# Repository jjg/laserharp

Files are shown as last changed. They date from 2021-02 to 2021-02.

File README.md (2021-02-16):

# laserharp

Play music by plucking strings made from laserbeams!

The instrument is composed of two separate components (laser bar and receiver) which are currently designed to be mounted in a 30" door frame.  A note is played when one of the eight beams is broken.

## Repository Structure
+ [docs](./docs/) - Component and other documentation captured from other sources
+ [experiments](./experiments/) - Mostly test code to figure out how to get things working
+ [images](./images/) - Photos and renderings
+ [models](./models/) - 3D model files for printable components
    + [laser_base.scad](./models/laser_base.scad) - Semi-paramentric laser LED holder with fine aiming adjustment
+ [firmware.py](./firmware.py) - Micropython firmware for the ESP32

## Current Status

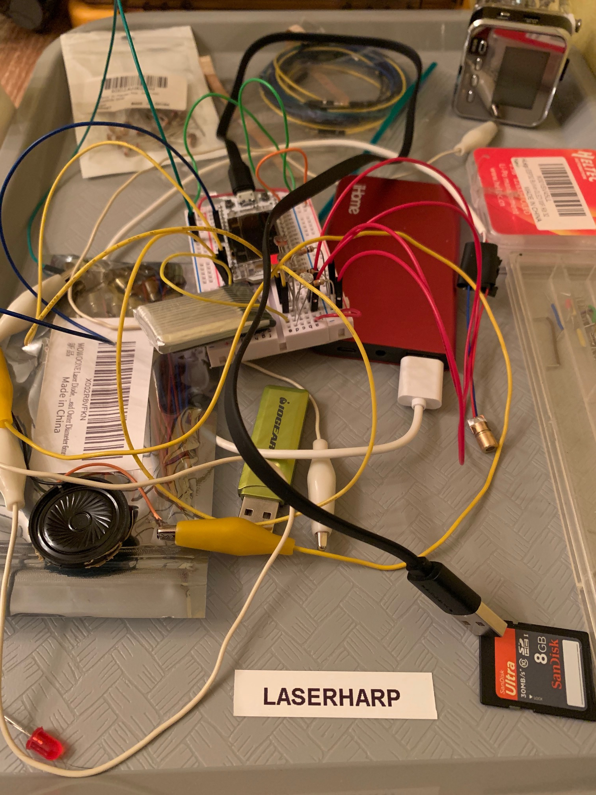
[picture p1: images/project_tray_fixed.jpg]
photo of tray full of parts


A functional (if not beautiful) prototype of the electronics and firmware has been completed and work is now focused on the physical components.  

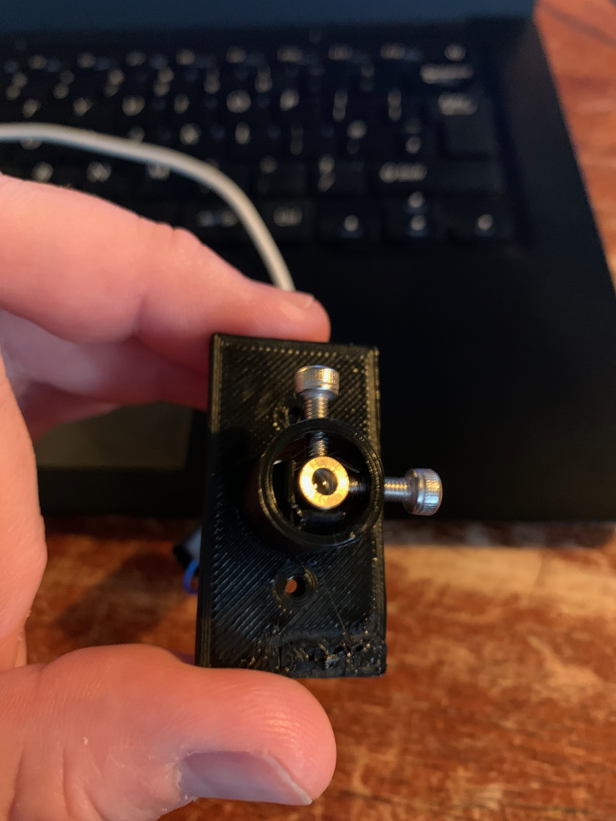
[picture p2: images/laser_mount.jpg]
photo of first version of laser mount


Once mounts for the lasers and sensors are complete these will be mounted on a full-size test rig to verify operation at full scale and test things like the difficulty of aiming the beams, etc.

## Theory of operation

8 laser beams (notes c to C) are aimed at 8 photoresisors connected on an ESP32.  The ESP32 scans the photoresistors and plays a note if the beam is interrupted.

## Hardware

* 1x [Heltec WiFi Kit 32](https://heltec.org/project/wifi-kit-32/)
* 1x 1000 mAh lithium battery
* 8x photoresistors
* 8x 10k resistors
* 1x 8ohm mini speaker
* 8x 5v ???mw red laser diodes

The ESP32 provides all the required functionality and the possibility for a wireless instrument interface in the future.  The Heltec board was selected because of its low-cost, compact construction and inclusion of a robust power supply (typically a weak point of most ESP32 designs).

TODO: add schematic

The photoresistors are connected to GPIO 32 through 39 using a voltage divider.  The speaker is simply connected between GPIO 14 and ground.

## Software

The current version of the [firmware](./firmware.py) scans each photoresistor once per second and when dark, plays the according note via PWM to a small speaker attached to pin 14.

## What's Next?

This completes the proof-of-concept stage so construction of the chassis using the selected components can begin.  The basic PWM "beeper" may be replaced with an amplified speaker or possibly an external WiFi/Bluetooth instrument connection.

## References

* https://www.instructables.com/Interfacing-Photoresistor-With-ESP32/
* https://docs.micropython.org/en/latest/library/pyb.DAC.html
* https://resource.heltec.cn/download/WiFi_Kit_32/WIFI_Kit_32_pinoutDiagram_V2.pdf
* https://micropython-on-wemos-d1-mini.readthedocs.io/en/latest/basics.html#beepers

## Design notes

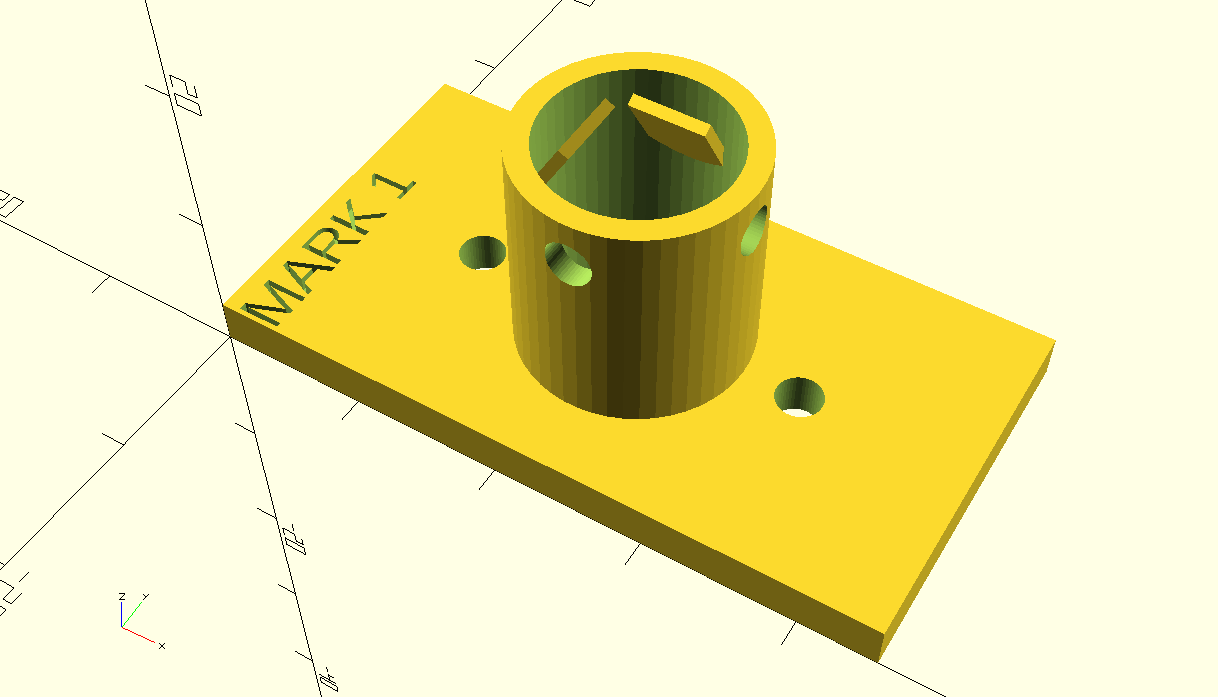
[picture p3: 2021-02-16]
images/laser_base.png

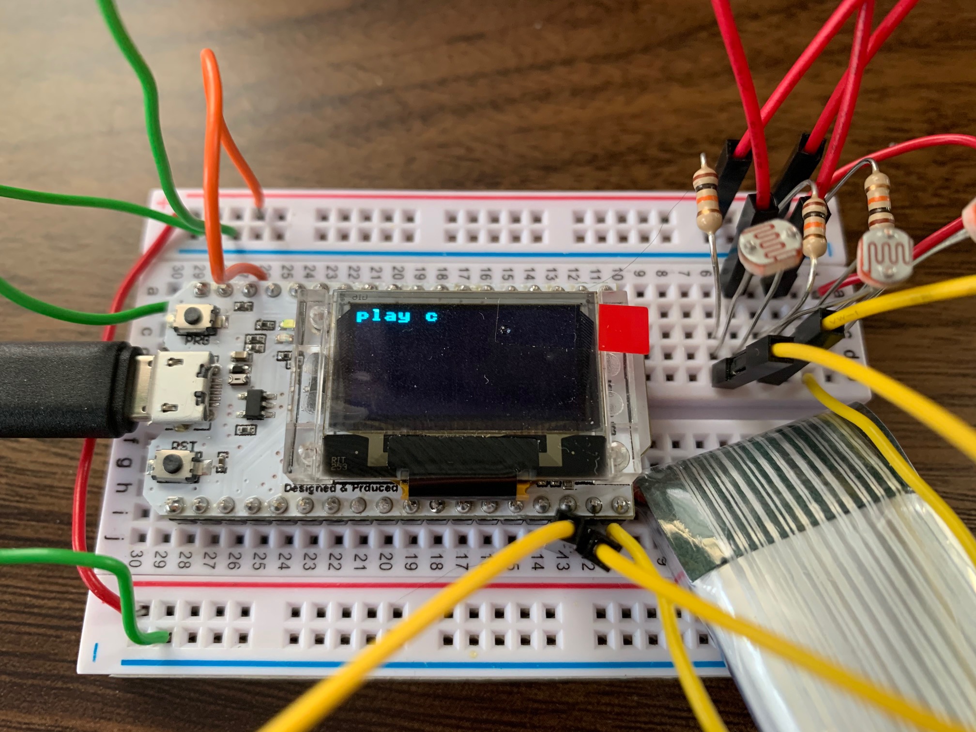
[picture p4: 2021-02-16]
images/oled_close_up.jpg

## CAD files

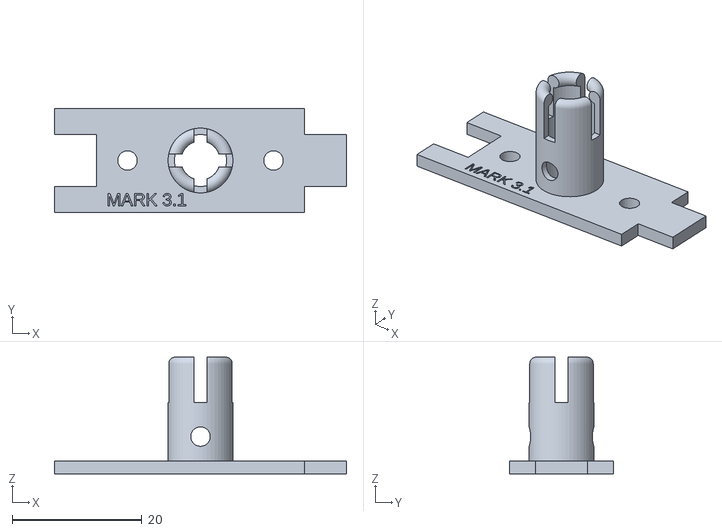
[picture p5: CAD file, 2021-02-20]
models/laser_base_m3_1.stl
45.0 x 16.0 x 18.0

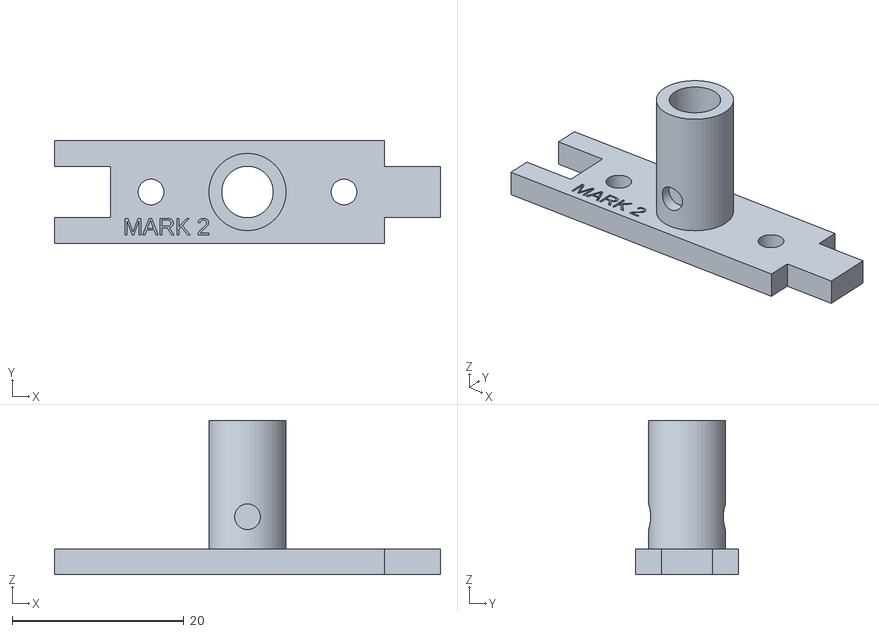
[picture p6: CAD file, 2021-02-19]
models/laser_base_m2.stl
45.0 x 12.0 x 18.0

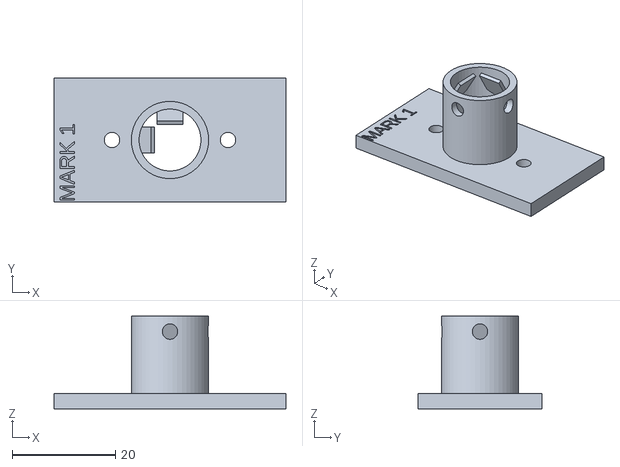
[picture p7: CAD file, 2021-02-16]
models/laser_base.stl
45.0 x 24.0 x 18.0

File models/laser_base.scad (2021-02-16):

VERSION = "MARK 1";
LASER_DIAMETER = 12; // actual: 6
LASER_LENGTH = 15; // actual: 14
BEAM_SPACING = 90;
SCREW_DIAMETER = 3;
WALL = 3;

$fn = 50;

difference(){
    
    // base
    cube([BEAM_SPACING / 2, LASER_DIAMETER * 2, WALL]);
    
    // mounting holes
    translate([BEAM_SPACING / 8, LASER_DIAMETER, -1]){
        cylinder(r=SCREW_DIAMETER / 2, h=6);
    }
    translate([(BEAM_SPACING / 2) - (BEAM_SPACING / 8), LASER_DIAMETER, -1]){
        cylinder(r=SCREW_DIAMETER / 2, h=6);
    }
    
    // laser insert hole
    translate([BEAM_SPACING / 4, LASER_DIAMETER, -1]){
        cylinder(r=LASER_DIAMETER / 2, h=6);
    }
    
    // version emblem
    translate([4,0,WALL-1]){
        rotate([0,0,90]){
            linear_extrude(1){
                text(VERSION, size=3);
            }
        }
    }
}

// laser holder
translate([BEAM_SPACING / 4, LASER_DIAMETER, WALL]){
    difference(){
        
        // post
        cylinder(r = (LASER_DIAMETER + WALL) / 2, h=LASER_LENGTH);
        
        // hole
        translate([0,0,-1]){
            cylinder(r = (LASER_DIAMETER / 2), h=LASER_LENGTH + 1);
        }
        
        // x adjustment screw hole
        translate([0,-WALL,LASER_LENGTH - WALL]){
            rotate([90, 0, 0]){
                cylinder(r=SCREW_DIAMETER / 2, h=WALL * 2);
            }
        }
        
        // y adjustment screw hole
        rotate([0,0,90]){
            translate([0,-WALL,LASER_LENGTH - WALL]){
                rotate([90, 0, 0]){
                    cylinder(r=SCREW_DIAMETER / 2, h=WALL * 2);
                }
            }
        }
    }
    
    // x spring
    translate([-WALL / 2 - 1,WALL * 2,LASER_LENGTH - (WALL * 2)]){
        rotate([30,0,0]){
            cube([WALL + 2, WALL / 4, WALL * 2]);
        }
    }
    
    // y spring
    rotate([0,0,90]){
        translate([-WALL / 2 - 1,WALL * 2,LASER_LENGTH - (WALL * 2)]){
            rotate([30,0,0]){
                cube([WALL + 2, WALL / 4, WALL * 2]);
            }
        }
    }
}

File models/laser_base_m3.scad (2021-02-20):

VERSION = "MARK 3.1";
LASER_DIAMETER = 8; // actual: 6
LASER_LENGTH = 15; // actual: 14
BEAM_SPACING = 90;
SCREW_DIAMETER = 3;
WALL = 2;

$fn = 50;

difference(){
    
    // base
    cube([BEAM_SPACING / 2, LASER_DIAMETER * 2, WALL]);
    
    // mounting holes
    translate([BEAM_SPACING / 8, LASER_DIAMETER, -1]){
        cylinder(r=SCREW_DIAMETER / 2, h=6);
    }
    translate([(BEAM_SPACING / 2) - (BEAM_SPACING / 8), LASER_DIAMETER, -1]){
        cylinder(r=SCREW_DIAMETER / 2, h=6);
    }
    
    // spacing cut-outs
    translate([-1,LASER_DIAMETER/2,-1]){
        cube([BEAM_SPACING / 12, LASER_DIAMETER, WALL + 2]);
    }
    translate([(BEAM_SPACING / 2 ) - (BEAM_SPACING / 12) + 1,LASER_DIAMETER+ (LASER_DIAMETER/2),-1]){
        cube([BEAM_SPACING / 12, LASER_DIAMETER, WALL + 2]);
    }
    translate([(BEAM_SPACING / 2 ) - (BEAM_SPACING / 12) + 1,- (LASER_DIAMETER / 2),-1]){
        cube([BEAM_SPACING / 12, LASER_DIAMETER, WALL + 2]);
    }
    
    // laser insert hole
    translate([BEAM_SPACING / 4, LASER_DIAMETER, -1]){
        cylinder(r=LASER_DIAMETER / 2, h=6);
    }
    
    // version emblem
    translate([8,1,WALL-1]){
        rotate([0,0,0]){
            linear_extrude(5){
                #text(VERSION, size=2);
            }
        }
    }
}

// laser holder
translate([BEAM_SPACING / 4, LASER_DIAMETER, WALL]){
    difference(){

        // post
        cylinder(r = (LASER_DIAMETER + WALL) / 2, h=LASER_LENGTH);
        
        // feed-through hole
        translate([0,0,-1]){
            cylinder(r = (LASER_DIAMETER / 2), h=LASER_LENGTH + 2);
        }
        
        // tension cut-outs
        translate([-LASER_DIAMETER,-WALL + (WALL / 2), LASER_LENGTH - (WALL * 3)]){
            cube([LASER_DIAMETER * 2, WALL, WALL * 4]);
        }
        rotate([0,0,90]){
            translate([-LASER_DIAMETER,-WALL + (WALL / 2), LASER_LENGTH - (WALL * 3)]){
                cube([LASER_DIAMETER * 2, WALL, WALL * 4]);
            }
        }
        
        // wiring hole
        translate([0,-WALL,(LASER_LENGTH / 4)]){
            rotate([90, 0, 0]){
                cylinder(r=SCREW_DIAMETER / 2, h=WALL * 2);
            }
        }
        
        // wiring hole
        rotate([0,0,180]){
            translate([0,-WALL,(LASER_LENGTH / 4)]){
                rotate([90, 0, 0]){
                    cylinder(r=SCREW_DIAMETER / 2, h=WALL * 2);
                }
            }
        } 
    }
    
    difference(){
        
        // top
        translate([0,0,LASER_LENGTH]){
            rotate_extrude(convexity = 10){
                translate([LASER_DIAMETER / 2, 0, 0]){
                    circle(r = 1);
                }
            }
        }
        
        // tension cut-outs (sloppy, we shouldn't have to repeat this here...
        translate([-LASER_DIAMETER,-WALL + (WALL / 2), LASER_LENGTH - (WALL * 3)]){
            cube([LASER_DIAMETER * 2, WALL, WALL * 4]);
        }
        rotate([0,0,90]){
            translate([-LASER_DIAMETER,-WALL + (WALL / 2), LASER_LENGTH - (WALL * 3)]){
                cube([LASER_DIAMETER * 2, WALL, WALL * 4]);
            }
        }
    }
}

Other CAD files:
models/laser_base_m3.stl
models/laser_base_m2.scad
models/laser_base_m4.scad

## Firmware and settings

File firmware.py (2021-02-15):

import time
import ssd1306

from machine import Pin, PWM, I2C, Timer

# Init display
oled_width = 128
oled_height = 64

i2c = I2C(scl=Pin(15), sda=Pin(4), freq=400000)
oled = ssd1306.SSD1306_I2C(oled_width, oled_height, i2c)

# Init beeper
beeper = PWM(Pin(14), freq=440, duty=512)
time.sleep(0.5)

sensors = [
    {
        "note": "c",
        "GPIO": 36,
        "freq": 262
    },
    {
        "note": "d",
        "GPIO": 37,
        "freq": 294
    },
    {
        "note": "e",
        "GPIO": 38,
        "freq": 330
    },
#    {
#        "note": "f",
#        "GPIO": 39,
#        "freq": 349
#    },
#    {
#        "note": "g",
#        "GPIO": 34,
#        "freq": 392
#    },
#    {
#        "note": "a",
#        "GPIO": 35,
#        "freq": 440
#    },
#    {
#        "note": "b",
#        "GPIO": 32,
#        "freq": 494
#    },
#    {
#        "note": "C",
#        "GPIO": 33,
#        "freq": 523
#    },
]

def scan(self):
    # TODO: We can monitor battery level on pin 13, so display that
    # (try setting pin mode to "analog" (otherwise only returns 1/0))
    # TODO: Buffer display so we only update it when needed
    oled.fill(0)
    # TODO: Remember note so we only change beeper frequency (or beeper.deinit()) when needed
    beeper.freq(0)
    
    # Enumerate sensor pins
    for sensor in sensors:
        # Select sensor 
        print("sensor note: " + sensor['note'])
        print("sensor_pin: " + str(sensor['GPIO']))
        sensor_pin = Pin(sensor["GPIO"], Pin.IN)
        
        # Read sensor
        sensor_value = sensor_pin.value()
        print("sensor_value: " + str(sensor_value))
        
        if sensor_value:
            print("silence")
            
        else:
            # Print status on oled
            print("note " + sensor['note'] + " is high")
            oled.text("play " + sensor['note'], 0, 0)
            
            # Play the note
            beeper.freq(sensor['freq'])
            
    oled.show()

# TODO: Find a way to cancel the timer when the script receives a "break",
# and consider providing a hardware interface to disable it
tim1 = Timer(0)
tim1.init(period=1000, mode=Timer.PERIODIC, callback=scan)

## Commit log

2021-02-13 Sensor scan working.!
2021-02-15 Notes on battery status.
2021-02-16 Mark 1 laser base.
    [laser_base.scad, laser_base.stl]
2021-02-19 Iteration 2 of the laser mount.
    [laser_base_m2.scad, laser_base_m2.stl]
2021-02-20 Add cuts to allow clip more flex.
    [laser_base_m3.scad, laser_base_m3_1.stl]
2021-03-06 Next iteration.
    [laser_base_m4.scad]
